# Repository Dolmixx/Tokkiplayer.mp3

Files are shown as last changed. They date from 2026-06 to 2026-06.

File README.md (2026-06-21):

# Tokkiplayer.mp3

Screenshot 2026-06-20 at 5 00 27 PM

Have you ever wanted a music player... perhaps themed around something perchance? Well now you can! The Tokkiplayer.mp3 is your friend, built with 2 speakers, LCD, RFID system, card storage, and a DFPlayer mini, it can easily play the songs you'd like! It has 5 buttons to pause/play (double press pause/play to shuffle), volume up and down, skip and go back so you can customize your music experience. It can store up to 3 seperate playlists that will activate when you tap the assigned card! 

Screenshot 2026-06-20 at 12 32 02 AM

Screenshot 2026-06-20 at 12 32 10 AM

# What does this do? 
It plays music silly! No but what makes this unique is that it has a RFID reader, that means you take the RFID cards and tap. When you first boot up the system, it'll be looking for new cards to assign playlists to and can store up to 3. (Feel free to look at the code to understand this better, or change it up to you!) It uses a DFPlayer mini to play songs off of a SD card. (Note: the songs must be mp3 and each title must start with a 3 digit number ie. "004_Attention" more information in assembly guide) In firmware there is a download that can go straight into your SD card filled with songs from an artist called NewJeans. (Feel free to use it as reference or use it to listen to some banger music) 

The cards then act as your "key" to playing a specific playlist, want to listen to NewJeans debut ep? Well tap the card. Don't want to listen to the same order of songs? Double press the play/pause button to shuffle! 

# Why does this exist?
Sometimes (all the time) I get tired of stupid ads, they interupt my music and when I'm getting into the zone. I just want to listen to my music in peace and as a person who adores the same songs on loop, this works perfectly to solve my problem. Who has the money to pay for a subscription? Not me. Also I only listen to a couple songs (my playlist is forever stuck at like 60 songs in which I loop the last 5 or something), so this is perfect! 

# Set Up
To set up simply load up the code on the Arduino, tap each card so that it is saved in the library then play your music by tapping the card! Change the volume with the buttons, shuffle by pressing the pause/play button twice, skip a song or go back to the previous one. Assembly is linked below for more information.

# Assembly + Setting up SD card
Here's the assembly [linked](https://github.com/Dolmixx/Tokkiplayer.mp3/blob/main/Production/Assembly.md)! It also provides some insight on how to format your SD card and set up.  

# Wiring diagram

Screenshot 2026-06-20 at 6 27 46 AM

# BOM 
| | Item | Quantity | Price per unit (CAD) | Total Price (CAD) | Note | Link |
|---|---|---|---|---|---|---|
| | DFPlayer Mini | 1 | 2.75 | 2.75 | | https://www.aliexpress.com/item/1005006166800318.html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 |
| | MFRC522 | 1 | 2.5 | 2.5 | comes with 1 RFID Card | https://www.aliexpress.com/item/1005005569224935.html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 |
| | Tact Switches | 50 | 0.0558 | 2.79 | | https://www.aliexpress.com/item/32801665868.html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 |
| | 16x2 LCD | 1 | 4.47 | 4.47 | | https://www.aliexpress.com/item/1005007825614260.html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 |
| | 3 watt 8 Ohm Speakers | 2 | 4.23 | 8.46 | Comes with one but you need to buy 2 | https://www.aliexpress.com/item/1005009465850637.html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 |
| | RFID Cards | 10 | 0.164 | 1.64 | You only need 3 total | https://www.aliexpress.com/item/1005006163193929.html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 |
| | Arduino UNO R3 | 1 | 4.01 | 4.01 | | https://www.aliexpress.com/item/1005005401781711.html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 |
| | Jumper wires | 40 of each | 0.0345 | 4.14 | Comes with FF, MF, and MM | https://www.aliexpress.com/item/32481623557.html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 |
| | Mini Breadboard | 1 | 0.8 | 0.8 | | https://www.aliexpress.com/item/32834323771.html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 |
| | M2 and M3 Screws | 230 | 0.03517391304 | 8.09 | | https://www.aliexpress.com/item/1005004833515587.html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 |
| | SD Card 32 GB | 1 | 9.9 | 9.9 | | https://www.amazon.ca/Class10-Memory-Extreme-Compatibility-Meomory/dp/B0GKPVR4RH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 |
| | AA Batteries | 4 | 0.4 | 1.6 | | https://www.aliexpress.com/item/1005011987720458.html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 |
| | 4X battery pack | 1 | 2,82 | 2.82 | | https://www.aliexpress.com/item/1005004197639879.html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 |
| | 9V battery | 1 | 3.97 | 3.97 | | https://www.walmart.ca/en/ip/Great-Value-9-V-6LR61-Alkaline-Battery-1-Pack-5-year-storage-life/6000196063059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 |
| | Snap cable connector  | 10 | 0.305 | 3.05 | Only need 1, comes with 10 | https://www.aliexpress.com/item/32874851624.html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 |
| | 3D printer | 1 | -- | -- | All parts are printed | https://ca.elegoo.com/products/elegoo-neptune-3-pro-fdm-3d-printer-225x225x280mm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 |
| Total | -- | -- | 28.94947391 | 49.55 | | |

# Credits

Websites/Tutorials that helped make this possible:

https://docs.arduino.cc/built-in-examples/digital/Debounce/

https://www.instructables.com/MP3-Player-With-Arduino-Using-DF-Player-Mini/

https://randomnerdtutorials.com/security-access-using-mfrc522-rfid-reader-with-arduino/

https://www.instructables.com/RFID-JukeBox-Using-Arduino-Uno-DFPlayerMini/

https://www.instructables.com/Arduino-MFRC522-RFID-READER/

Cad Models used: 

[Arduino UNO](https://www.printables.com/model/358867-arduino-uno-3d-model-stp/files) By: Ludvig Broomé

[LCD 16x2](https://www.printables.com/model/1235460-1602a-display-model) By: Даниил Неважно

[DFPlayer](https://grabcad.com/library/dfplayer-mini-3) By: Danilo Diaz

[RC522](https://grabcad.com/library/modulo-sensor-rfid-rc522-rf-ic-1) By: UNIT ELECTRONICS 

[Speakers](https://grabcad.com/library/3-watt-8-ohm-mini-speaker-1) By: Jose Pedraza 

[Buttons](https://grabcad.com/library/push-button-6x6x5mm-4pin-1/details?folder_id=6790054) By: Yusuf Savaş

[Battery](https://grabcad.com/library/9v-battery--1) By: Dave Cancilier

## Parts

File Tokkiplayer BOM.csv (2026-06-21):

 | Item | Quantity | Price per unit (CAD) | Total Price (CAD) | Note | Link
 | DFPlayer Mini | 1 | 2.75 | 2.75 |  | https://www.aliexpress.com/item/1005006166800318.html?curPageLogUid=esrEVw5hCwAk
 | MFRC522 | 1 | 2.5 | 2.5 | comes with 1 RFID Card | https://www.aliexpress.com/item/1005005569224935.html?curPageLogUid=bReddcnZ4Y6q
 | Tact Switches | 50 | 0.0558 | 2.79 |  | https://www.aliexpress.com/item/32801665868.html?curPageLogUid=07qkF7u8c6qe
 | 16x2 LCD | 1 | 4.47 | 4.47 |  | https://www.aliexpress.com/item/1005007825614260.html?curPageLogUid=qqjOpZGK9mT3
 | 3 watt 8 Ohm Speakers | 2 | 4.23 | 8.46 | Comes with one but you need to buy 2 | https://www.aliexpress.com/item/1005009465850637.html
 | RFID Cards | 10 | 0.164 | 1.64 | You only need 3 total | https://www.aliexpress.com/item/1005006163193929.html?curPageLogUid=ps5rMU4dKvHw
 | Arduino UNO R3 | 1 | 4.01 | 4.01 |  | https://www.aliexpress.com/item/1005005401781711.html?curPageLogUid=v5ktPjw5AXjX
 | Jumper wires | 40 of each | 0.0345 | 4.14 | Comes with FF, MF, and MM | https://www.aliexpress.com/item/32481623557.html?curPageLogUid=4Euovy9Lhezh
 | Mini Breadboard | 1 | 0.8 | 0.8 |  | https://www.aliexpress.com/item/32834323771.html?curPageLogUid=pX77Ioft9QoW
 | M2 and M3 Screws | 230 | 0.03517391304 | 8.09 |  | https://www.aliexpress.com/item/1005004833515587.html?curPageLogUid=QxA29IVfwcYp
 | SD Card 32 GB | 1 | 9.9 | 9.9 |  | https://www.amazon.ca/Class10-Memory-Extreme-Compatibility-Meomory/dp/B0GKPVR4RH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
 | AA Batteries | 4 | 0.4 | 1.6 |  | https://www.aliexpress.com/item/1005011987720458.html?curPageLogUid=UbjYgcGQ235k
 | 4X battery pack | 1 | 2,82 | 2.82 |  | https://www.aliexpress.com/item/1005004197639879.html?curPageLogUid=ckLS0CoZgpTw
 | 9V battery | 1 | 3.97 | 3.97 |  | https://www.walmart.ca/en/ip/Great-Value-9-V-6LR61-Alkaline-Battery-1-Pack-5-year-storage-life/6000196063059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
 | Snap cable connector | 10 | 0.305 | 3.05 | Only need 1, comes with 10 | https://www.aliexpress.com/item/32874851624.html?curPageLogUid=SwmAeShmx63n
 | 3D printer | 1 | -- | -- | All parts are printed | https://ca.elegoo.com/products/elegoo-neptune-3-pro-fdm-3d-printer-225x225x280mm?variant=47691001331990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
Total | -- | -- | 28.94947391 | 49.55

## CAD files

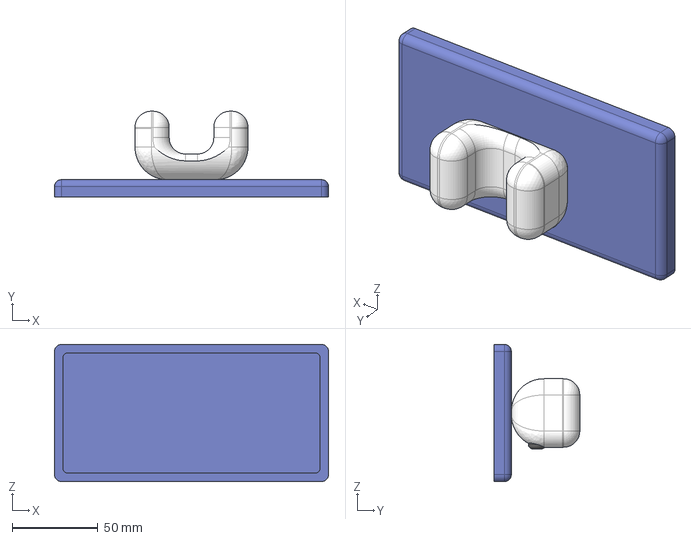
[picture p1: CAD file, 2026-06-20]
Production/CAD Files/STEP Files/Music Player Lid.step
160.0 x 50.0 x 80.0 mm

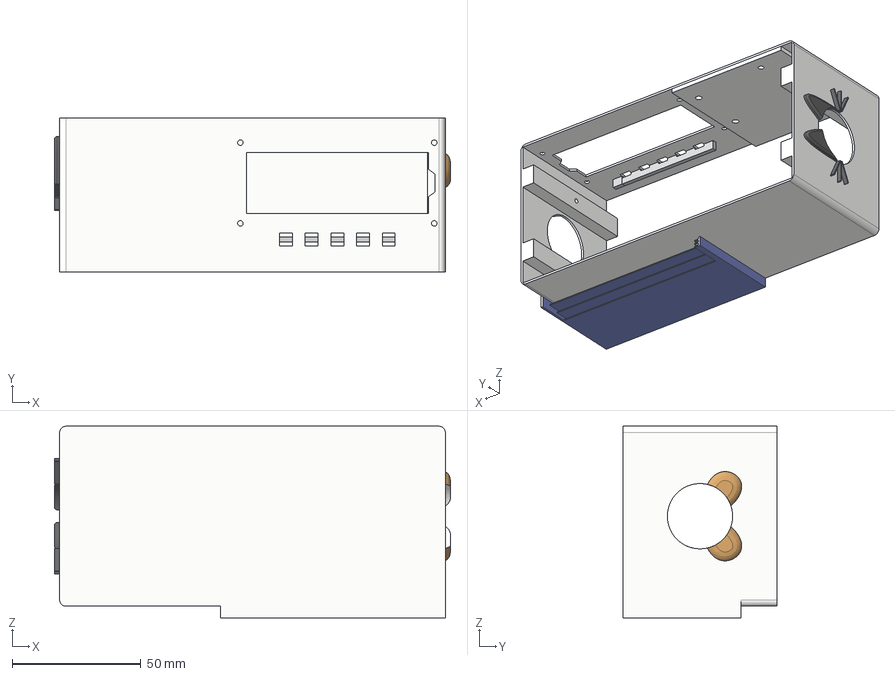
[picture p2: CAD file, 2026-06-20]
Production/CAD Files/STEP Files/Music Player Container.step
154.0 x 60.0 x 74.5 mm

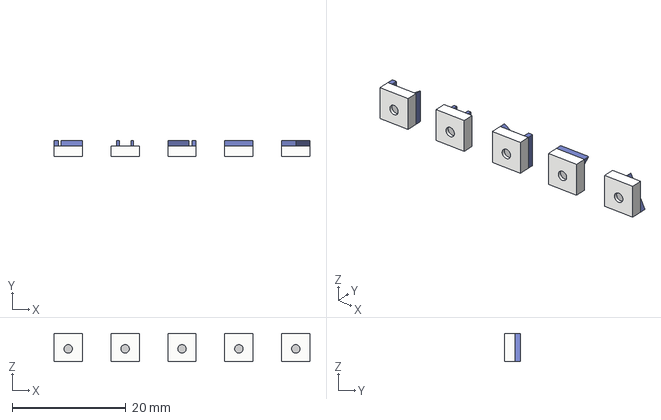
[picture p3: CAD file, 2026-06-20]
Production/CAD Files/STEP Files/Buttons.step
45.0 x 2.80 x 5.00 mm

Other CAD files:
Production/CAD Files/F3D Files/Buttons.f3d
Production/CAD Files/F3D Files/Music Player Container.f3d
Production/CAD Files/F3D Files/Music Player Lid.f3d

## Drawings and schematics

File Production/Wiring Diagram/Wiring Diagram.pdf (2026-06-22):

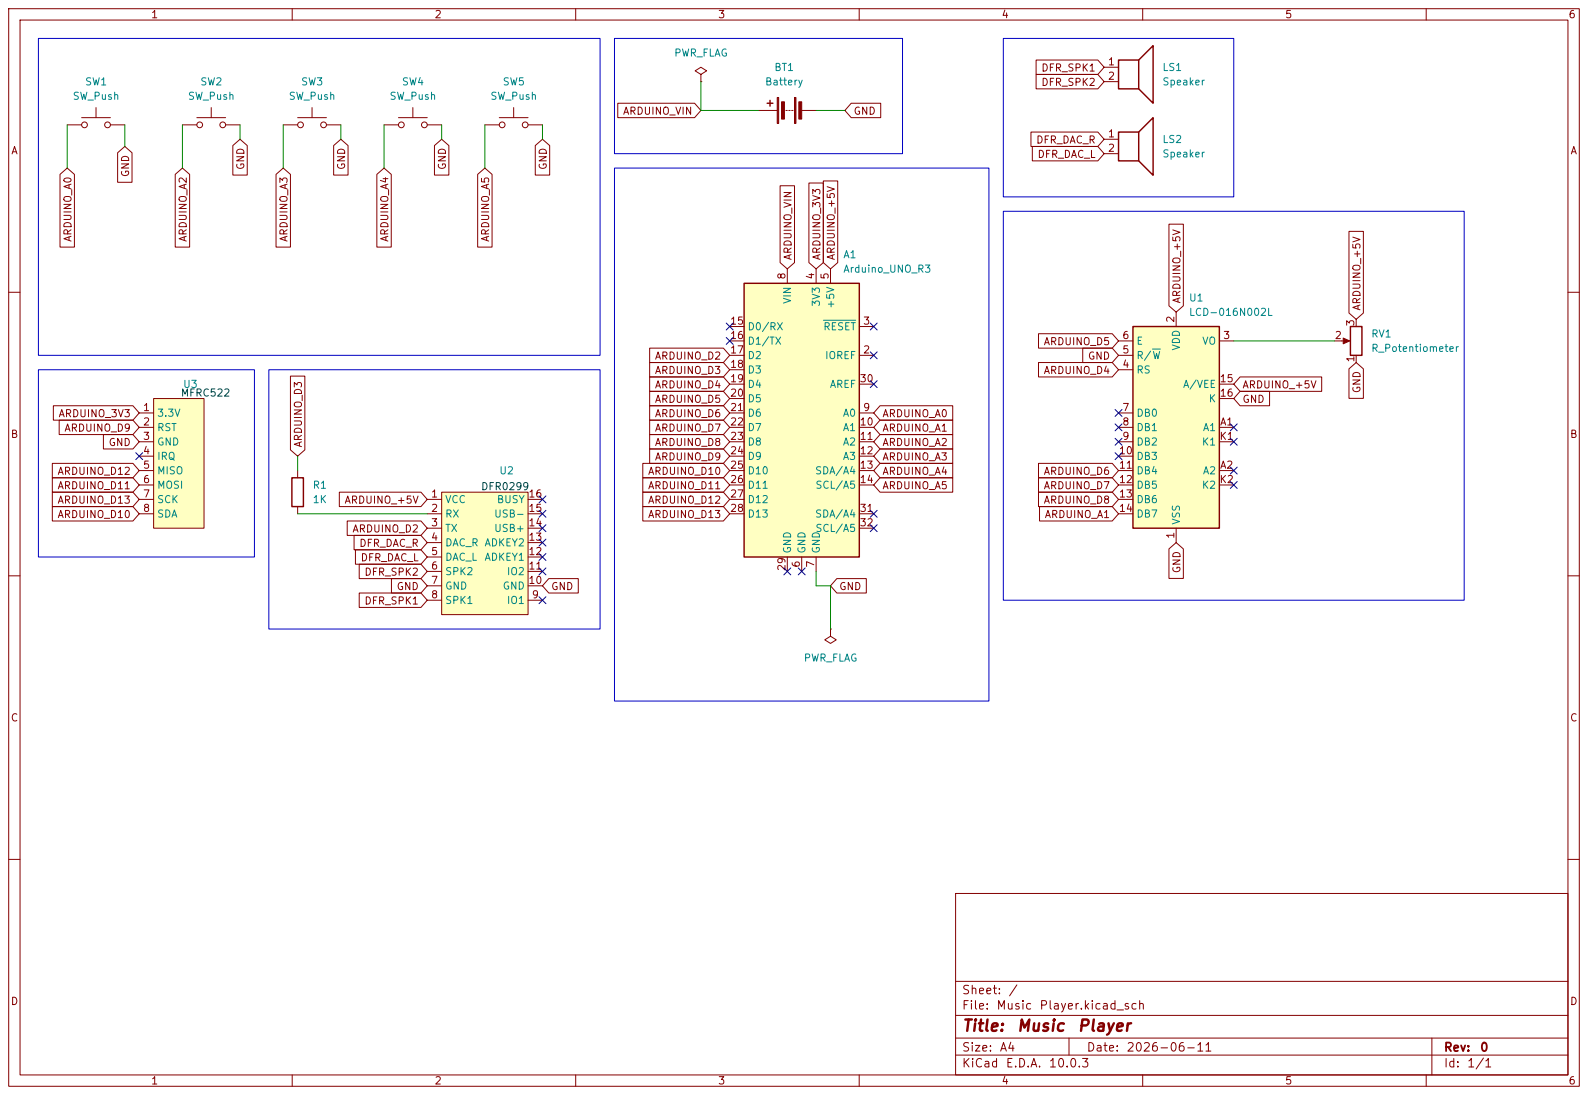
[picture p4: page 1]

Size: A4 | Rev: 0
KiCad E.D.A. 10.0.3 | Id: 1/1

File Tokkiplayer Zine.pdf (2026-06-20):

# + Tokkiplayer.mp3 +

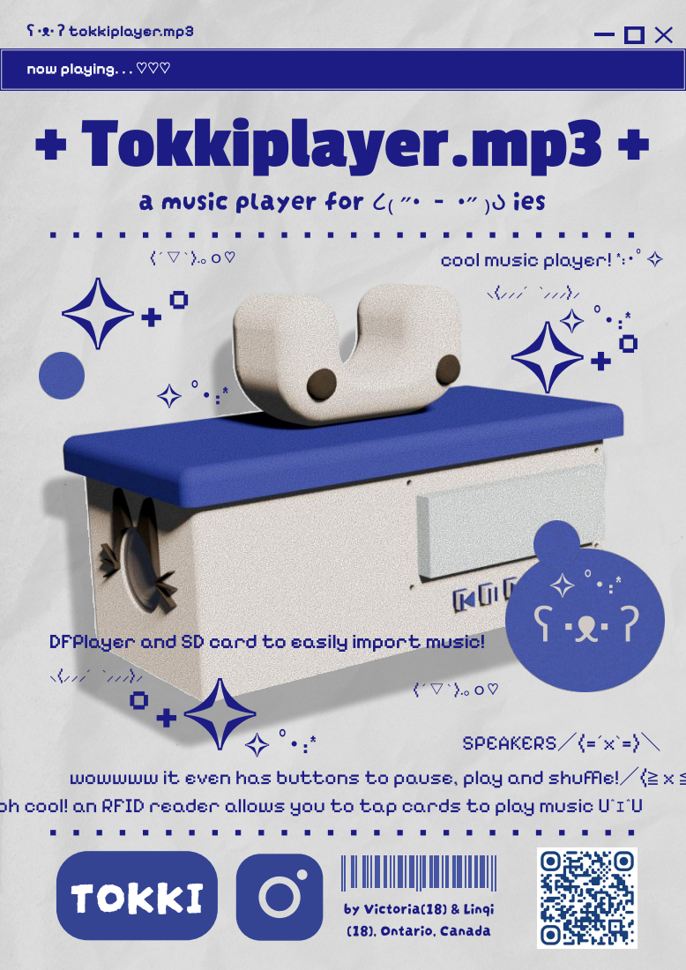
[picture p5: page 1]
ʕ •ᴥ• ʔ tokkiplayer.mp3; now playing. . . ♡♡♡; DFPlayer and SD card to easily import music!; SPEAKERS／(=´x`=)＼; TOKKI; by Victoria(18) & Linqi; (18), Ontario, Canada

a music player for ૮₍ ˶• - •˶ ₎ა ies

cool music player! *:･ﾟ✧

wowwww it even has buttons to pause, play and shuffle!／(≧ x ≦)＼
oh cool! an RFID reader allows you to tap cards to play music U^ｪ^U

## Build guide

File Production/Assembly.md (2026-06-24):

# Assembly + Set Up guide

So you want to make this super cool music player? You're in luck! (When adding each electrical component, ensure you have wired it properly according to the wiring schematic. Moreover, it is advised to wire directly before attaching the specific piece for ease.) 

1. The Arduino
The arduino UNO R3 should sit on the left side of the container. It does not need to be attached to anything as this build does not move around. If you feel inclined to, feel free to use your own methods, but it is not required for this.

Screenshot 2026-06-20 at 12 28 49 AM

2. MFRC522
This attaches with 4 screws, you will need to attached this "backwards". Don't worry it still works! this just makes it so it is a cleaner design.

Screenshot 2026-06-20 at 12 29 16 AM

3. DFPlayer
Similar to the arduino, the DFPlayer does not need to be attached to anything except a mini breadboard. Breadboards typically come with adhesive on the back for you to stick it to things. Feel free to sick it to the bottom although that is not needed as stated earlier this build does not move!

Screenshot 2026-06-20 at 12 29 30 AM

Additionally the battery pack can be placed in this spot ontop of the 9V battery if you move the DFPlayer to sit ontop of the arduino. It is reccomended you add this last though! 

Screenshot 2026-06-20 at 8 27 19 PM

Screenshot 2026-06-20 at 7 49 34 PM

4. The LCD
It is better to attach the LCD first before attaching the speakers as they may get in the way. Similar to the MFRC522, the LCD also attaches via 4 screws.

Screenshot 2026-06-20 at 12 31 00 AM

Screw from the outside, for reference on what the outside is, it is pictured below. 

Screenshot 2026-06-20 at 12 38 22 AM

5. The speakers
There are 2 speakers, each with 2 screws to attach. Whether you would like the wired side to face up or down is up to you!

Screenshot 2026-06-20 at 12 29 55 AM

Screenshot 2026-06-20 at 12 30 05 AM

6. The RFID cards and SD card
You may have noticed this build uses RFID! There are 3 openings at the back for you to store those cards. Feel free to decorate the cards if you'd like to match whatever music you want to listen to. (More information on SD card set up below)

Screenshot 2026-06-20 at 12 30 26 AM

7. Buttons
Almost done now! The buttons can be placed into the holes at the front

Screenshot 2026-06-20 at 12 31 31 AM

Screenshot 2026-06-20 at 12 31 35 AM

after placing them in, place the button covers on top to know which each button does! 

Screenshot 2026-06-20 at 12 31 41 AM

The covers should sit snug on the button, NOT touching the 4 smaller circles on each button. To check, press down on each of them gently. 

Screenshot 2026-06-20 at 12 48 39 AM

8. The lid
This one is self explanatory! Just place the lid on top, the eyes of the creature should look forward!
Screenshot 2026-06-20 at 12 32 02 AM

Yay! Now you have a music player. 

# SD CARD SET UP

The SD card can be placed directly into the DFPlayer. Ensure you have songs on your SD card formatted properly with 4 digit numbers at the begining and the files be mp3. ie. "0001_Attention" note that this is only if you plan on NOT having multiple playlists. 

If you plan on having up to 3 playlists, put your songs in different files (one file for each playlist) and rename the file "01", "02".. you get the point. The songs should start with a THREE digit number instead of a four digit number. This is because you have placed it in a folder. (There is a file in production that already has a bunch of NewJeans songs downloaded in that MP3 format if you want something to reference off of/are confused!)

Additionally, to customize further if you'd like to have the LCD display the proper titles for your songs, go into the firmware code and look at the 3 playlists. The name of the playlist shouldn't be changed! But the names in the list can be, and feel free to add more as the code will adjust to the amount you add! (But i do reccomend listening to some NewJeans :D) 

Below is what your SD card should look like!

Screenshot 2026-06-24 at 9 35 53 AM

Screenshot 2026-06-24 at 9 36 10 AM

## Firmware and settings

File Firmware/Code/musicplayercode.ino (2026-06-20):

// libraries
#include <MFRC522.h>
#include <LiquidCrystal.h>
#include <DFRobotDFPlayerMini.h>
#include <SoftwareSerial.h>
#include <SPI.h>

// LCD
LiquidCrystal lcd(4, 5, 6, 7, 8, A1);

// MFRC522
#define RST 9
#define SDA 10
MFRC522 mfrc522(RST, SDA);

// buttons
#define PAUSE A0
#define PREV A2
#define NEXT A3
#define UP A4
#define DOWN A5

// DFPlayer
#define RX 2
#define TX 3
SoftwareSerial softwareSerial(RX, TX);
DFRobotDFPlayerMini DFPlayer;

// playlists
const String GetUp_playlist[] = {
  "New Jeans", "Super Shy", "ETA", "Cool With You", "Get Up", "ASAP"
};

const String New_Jeans_playlist[] = {
  "Attention", "Hype Boy", "Cookie", "Hurt"
};

const String Singles_playlist[] = {
  "Ditto", "OMG", "Zero", "How Sweet", "Bubble Gum", "Supernatural", "Right Now", "GODS"
};

// RFID storage
byte card1[4];
byte card2[4];
byte card3[4];
bool card1_info = false;
bool card2_info = false;
bool card3_info = false;
bool start = false;

// vars
int playlists = 1;
int tracknum = 1;
int volume = 15;
bool paused = false;
int total = sizeof(GetUp_playlist) / sizeof(GetUp_playlist[0]);

unsigned long debounce = 0;
unsigned long debouncedelay = 50;
unsigned long pauseclick = 0;
bool pausepending = false;
const int doubleclick = 500;

// helper
void playTrack() {
  DFPlayer.playFolder(playlists, tracknum);

  lcd.clear();
  lcd.setCursor(0, 0);
  lcd.print("Playing: ");
  printname();
}

void printname() {
  lcd.setCursor(0, 1);
  if (playlists == 1) {
    lcd.print(GetUp_playlist[tracknum - 1]);
  } else if (playlists == 2) {
    lcd.print(New_Jeans_playlist[tracknum - 1]);
  } else if (playlists == 3) {
    lcd.print(Singles_playlist[tracknum - 1]);
  }
}

bool uidcheck(byte scanned[], byte saved[]) {
  for (byte i = 0; i < 4; i++) {
    if (scanned[i] != saved[i]) {
      return false;
    }
  }
  return true;
}
// main
void setup() {
  Serial.begin(9600);
  softwareSerial.begin(9600);

  SPI.begin();
  mfrc522.PCD_Init();
  randomSeed(analogRead(A6));

  lcd.begin(16, 2);
  lcd.print("Scan a card!");
  lcd.setCursor(0, 1);

  pinMode(PAUSE, INPUT_PULLUP);
  pinMode(PREV, INPUT_PULLUP);
  pinMode(NEXT, INPUT_PULLUP);
  pinMode(UP, INPUT_PULLUP);
  pinMode(DOWN, INPUT_PULLUP);

  if (DFPlayer.begin(softwareSerial)) {
    DFPlayer.volume(volume);
  }
}

void loop() {
  if (mfrc522.PICC_IsNewCardPresent() &&
      mfrc522.PICC_ReadCardSerial()) {
    if (!card1_info) {
      memcpy(card1, mfrc522.uid.uidByte, 4);
      card1_info = true;
      lcd.clear();
      lcd.print("Card 1 Saved");
    }
    else if (!card2_info) {
      memcpy(card2, mfrc522.uid.uidByte, 4);
      card2_info = true;
      lcd.clear();
      lcd.print("Card 2 Saved");
    }
    else if (!card3_info) {
      memcpy(card3, mfrc522.uid.uidByte, 4);
      card3_info = true;
      lcd.clear();
      lcd.print("Card 3 Saved");

      start = true;

      delay(1000);
      lcd.clear();
      lcd.print("Ready!");
    }

    else if (start) {
      if (uidcheck(mfrc522.uid.uidByte, card1)) {
        playlists = 1;
        total = sizeof(GetUp_playlist) / sizeof(GetUp_playlist[0]);
        lcd.clear();
        lcd.print("Get Up EP");
      } 
      else if (uidcheck(mfrc522.uid.uidByte, card2)) {
        playlists = 2;
        total = sizeof(New_Jeans_playlist) / sizeof(New_Jeans_playlist[0]);
        lcd.clear();
        lcd.print("New Jeans EP");
      } 
      else if (uidcheck(mfrc522.uid.uidByte, card3)) {
        playlists = 3;
        total = sizeof(Singles_playlist) / sizeof(Singles_playlist[0]);
        lcd.clear();
        lcd.print("Singles");
      }
      tracknum = 1;
      paused = false;
      delay(500);
      playTrack();
    }
    mfrc522.PICC_HaltA();
    mfrc522.PCD_StopCrypto1();
  }

  if ((millis() - debounce) > debouncedelay) {
    if (digitalRead(PAUSE) == LOW) {
      if (pausepending && (millis() - pauseclick < doubleclick)) {
        tracknum = random(1, total + 1);
        lcd.clear();
        lcd.print("Shuffling...");
        delay(500);
        playTrack();
        pausepending = false;

      } else {
        pausepending = true;
        pauseclick = millis();
      }
      debounce = millis();
    }

    if (digitalRead(NEXT) == LOW) {
      tracknum ++;
      if (tracknum > total)
        tracknum = 1;
      playTrack();
      debounce = millis();
    }

    if (digitalRead(PREV) == LOW) {
      tracknum --;
      if (tracknum < 1)
        tracknum = total;
      playTrack();

      debounce = millis();
    }

    if (digitalRead(UP) == LOW) {
      if (volume < 30) {
        volume++;
        DFPlayer.volume(volume);
      }
      lcd.clear();
      lcd.print("Volume: ");
      lcd.print(volume);

      debounce = millis();
    }

    if (digitalRead(DOWN) == LOW) {
      if (volume > 0) {
        volume--;
        DFPlayer.volume(volume);
      }
      lcd.clear();
      lcd.print("Volume: ");
      lcd.print(volume);

      debounce = millis();
    }

    if (pausepending &&
        (millis() - pauseclick >= doubleclick)) {
      if (paused) {
        DFPlayer.start();
        paused = false;
        lcd.clear();
        lcd.print("Playing");
      } else {
        DFPlayer.pause();
        paused = true;
        lcd.clear();
        lcd.print("Paused");
      }
      printname();
      pausepending = false;
    }
  }
}

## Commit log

2026-06-20 Upload CAD and misc
    [Buttons.f3d, Buttons.step, Music Player Container.f3d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]
2026-06-21 Update BOM
    [Tokkiplayer BOM.csv]
